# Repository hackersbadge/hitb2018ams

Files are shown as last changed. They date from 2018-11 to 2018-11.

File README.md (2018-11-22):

# Hacker's Badge for Hack In The Box 2018, Amsterdam

- [x] Hardware: WhiteA10n3
- [x] Code: KLKS + xwings (partial)

* MCU: STM32F103
* Flash: W25Q32
* 1.3 inch OLED
* 433Mhz RF Receiver
* IR Receiver
* 6 Buttons (Up, Down, Left, Right, OK, ESC)
* 6 x RGB LED

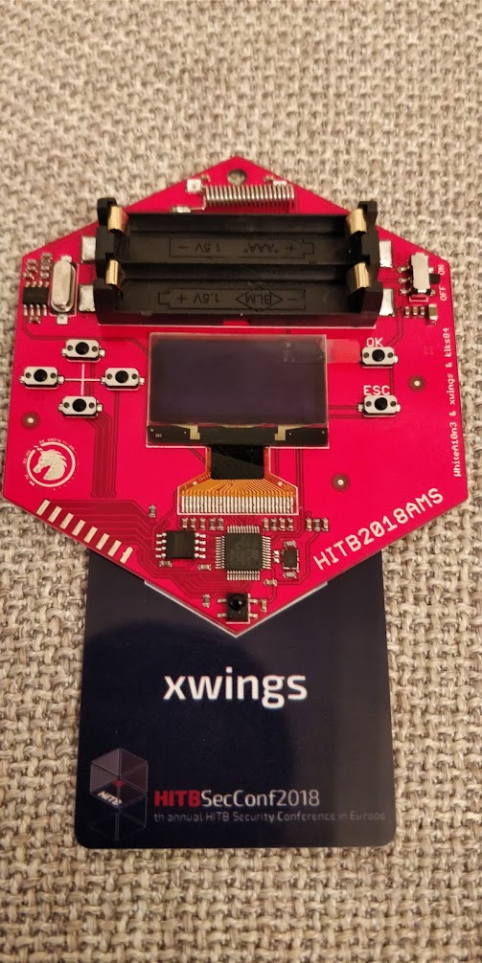
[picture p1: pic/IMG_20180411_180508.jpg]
badge0
      
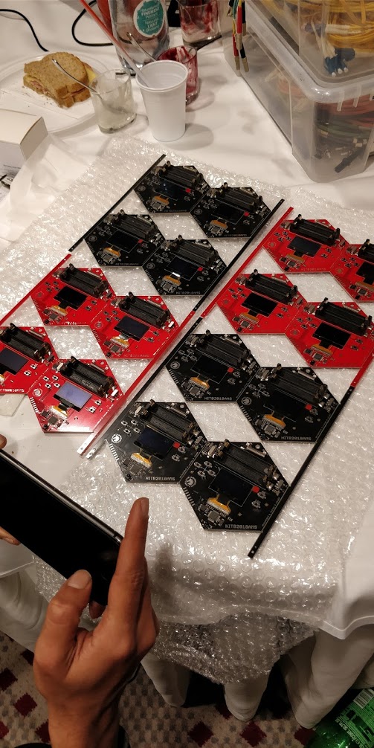
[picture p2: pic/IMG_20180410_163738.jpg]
badge1


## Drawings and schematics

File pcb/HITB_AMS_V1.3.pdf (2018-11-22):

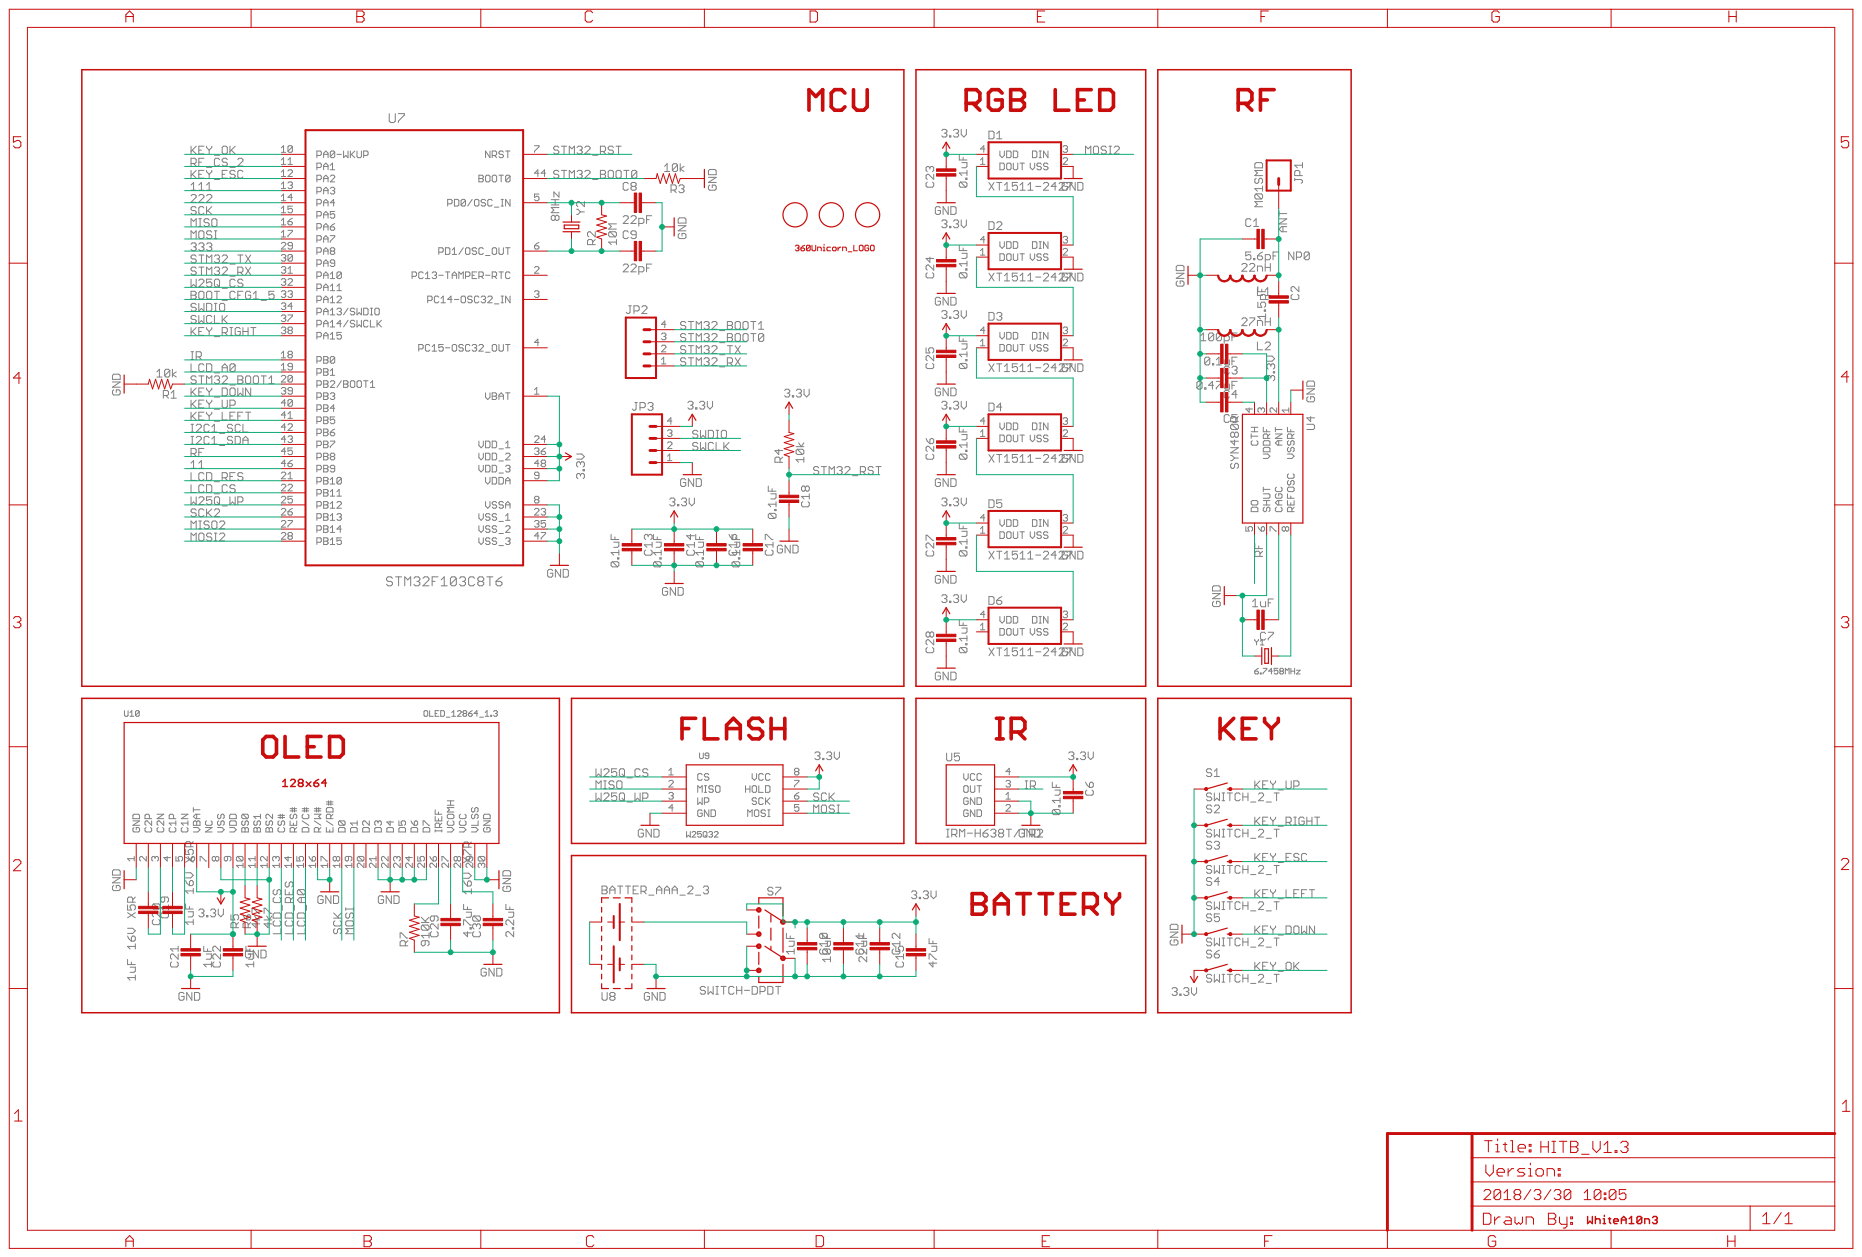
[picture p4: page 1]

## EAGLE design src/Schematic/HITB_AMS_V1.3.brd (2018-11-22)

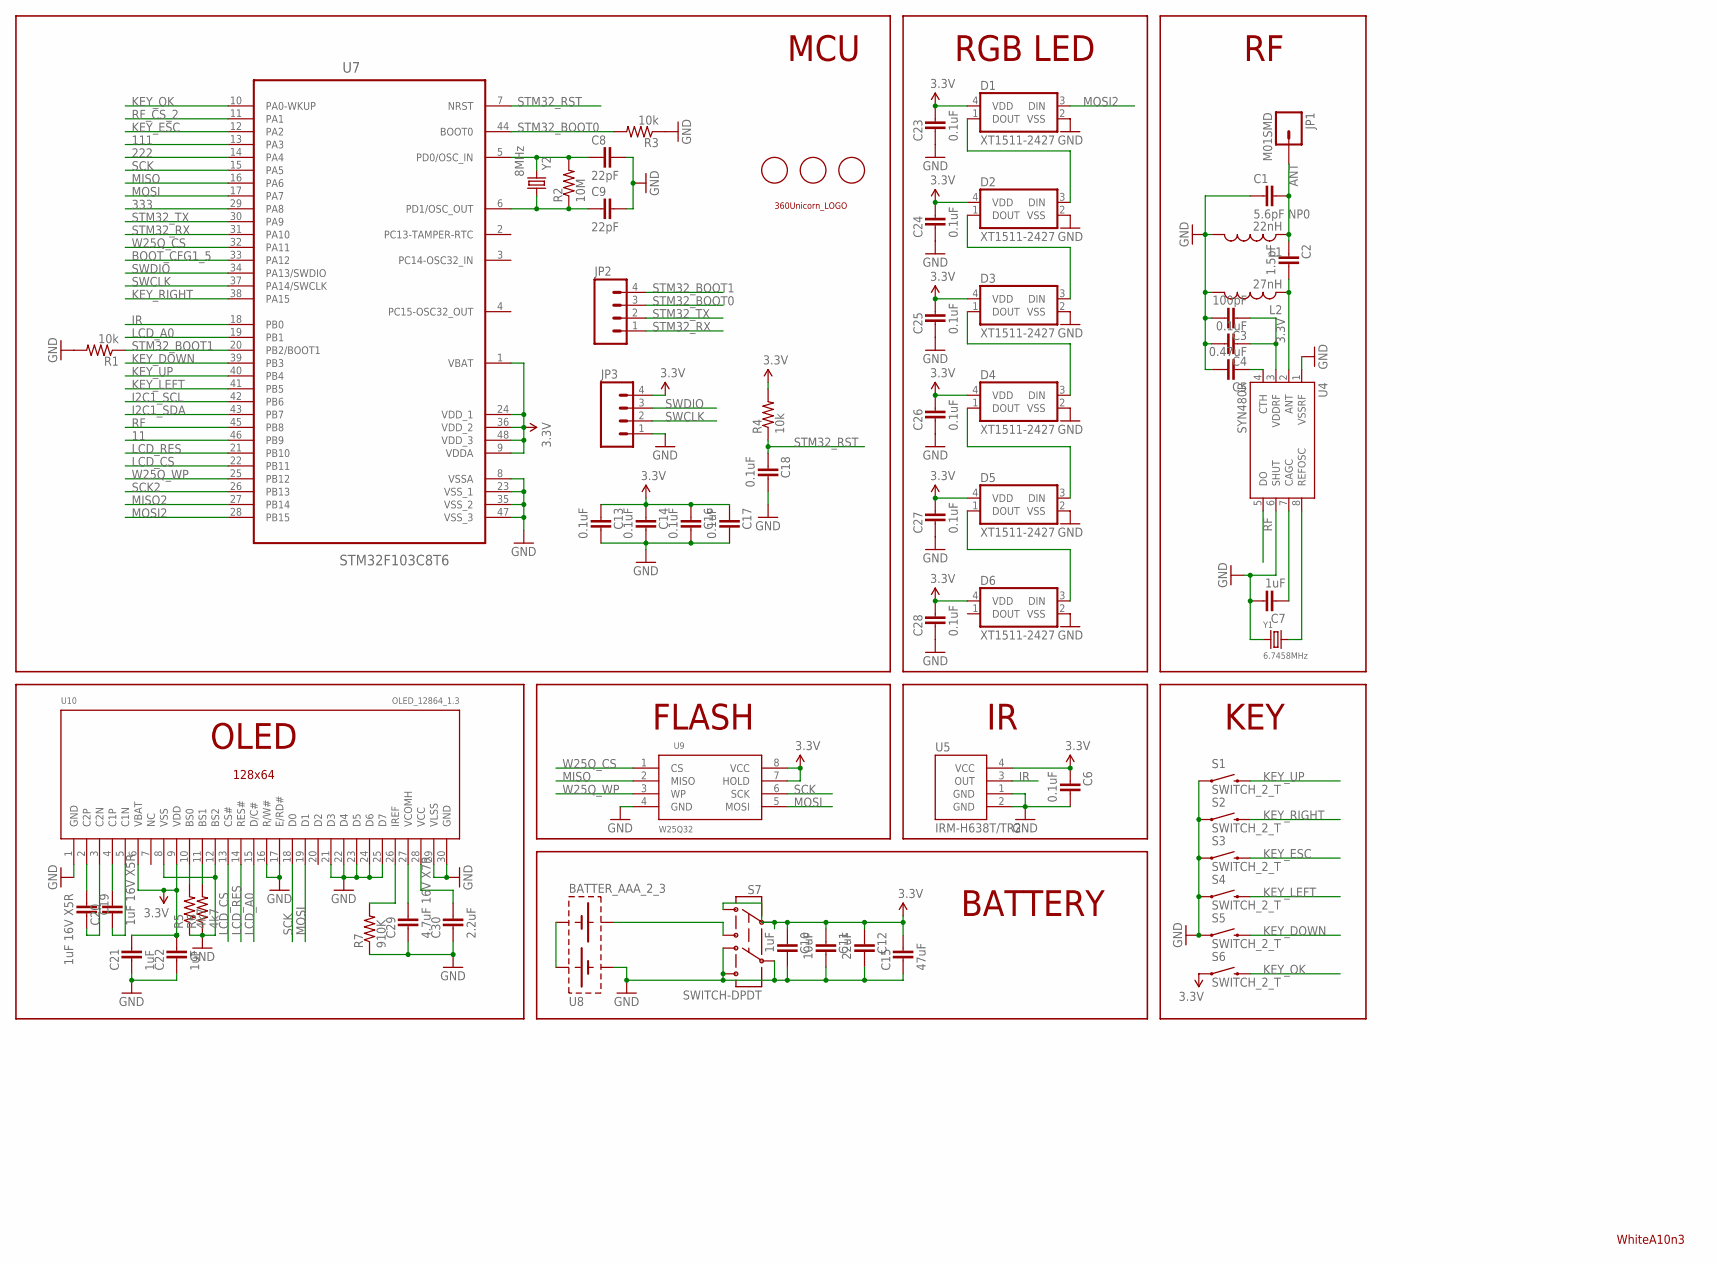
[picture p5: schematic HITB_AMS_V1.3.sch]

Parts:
C1: 5.6pF NP0; 0603-CAP
C2: 1.5pF; 0603-CAP
C3: 100pF; 0603-CAP
C4, C6, C13, C14, C16, C17, C18, C23, C24, C25, C26, C27, C28: 0.1uF; 0603-CAP
C5: 0.47uF; 0603-CAP
C7, C10, C21, C22: 1uF; 0603-CAP
C8, C9: 22pF; 0603-CAP
C11: 10uF; 0603-CAP
C12: 22uF; 0603-CAP
C15: 47uF; 1206
C19, C20: 1uF 16V X5R; 0603-CAP
C29: 4.7uF 16V X7R; 0603-CAP
C30: 2.2uF; 0603-CAP
D1, D2, D3, D4, D5, D6: XT1511-2427; RGB_2427
JP1: M01SMD; LUXEON-PAD
JP2, JP3: M04_TEST_2; 1X04_TEST_2
L1: 22nH; 0603
L2: 27nH; 0603
R1, R3, R4: 10k; 0603-RES
R2: 10M; 0603-RES
R5, R6: 4k7; 0603-RES
R7: 910K; 0603-RES
S1, S2, S3, S4, S5, S6: SWITCH_2_T; BUTTON_TSSURX
S7: SWITCH-DPDT; MSS22D18
U1, U2, U3: FIDUCIALMOUNT; FIDUCIA-MOUNT
U4: SYN480R; SO08
U5: IRM-H638T/TR2; IR_RECEIVE
U6: 360UNICORN_LOGO_0.8_STOP; 360UNICORN_S0.8
U7: STM32F103C8T6; TQFP48
U8: BATTER_AAA_2_3; BATTER_AAA_3
U9: W25Q32; SO08-EIAJ
U10: OLED_12864_1.3
Y1: 6.7458MHz; HC49UP
Y2: 8MHz; CRYSTAL-SMD-3225

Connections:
3.3V: C3.2, C4.2, C6.2, C10.2, C11.2, C12.2, C13.2, C14.2, C15.1, C16.2, C17.2, C21.1, C22.1, C23.1, C24.1, C25.1, C26.1, C27.1, C28.1, D1.4 (VDD), D2.4 (VDD), D3.4 (VDD), D4.4 (VDD), D5.4 (VDD), D6.4 (VDD), JP3.4, R4.2, S6.P$1 (1), S7.1, S7.2, U4.3 (VDDRF), U5.4 (VCC), U7.1 (VBAT), U7.9 (VDDA), U7.24 (VDD_1), U7.36 (VDD_2), U7.48 (VDD_3), U9.7 (HOLD), U9.8 (VCC), U10.6 (VBAT), U10.9 (VDD)
11: U7.46 (PB9)
111: U7.13 (PA3)
222: U7.14 (PA4)
333: U7.29 (PA8)
ANT: C1.1, C2.2, JP1.P$1, L1.1
BOOT_CFG1_5: U7.33 (PA12)
GND: C1.2, C3.1, C4.1, C5.1, C6.1, C7.1, C8.1, C9.1, C10.1, C11.1, C12.1, C13.1, C14.1, C15.2, C16.1, C17.1, C18.1, C21.2, C22.2, C23.2, C24.2, C25.2, C26.2, C27.2, C28.2, C29.2, C30.2, D1.2 (VSS), D2.2 (VSS), D3.2 (VSS), D4.2 (VSS), D5.2 (VSS), D6.2 (VSS), JP3.1, L1.2, L2.2, R1.2, R3.1, R5.1, R6.1, R7.1, S1.P$1 (1), S2.P$1 (1), S3.P$1 (1), S4.P$1 (1), S5.P$1 (1), S7.4, S7.5, S7.6, U4.1 (VSSRF), U4.6 (SHUT), U5.1 (GND), U5.2 (GND), U7.8 (VSSA), U7.23 (VSS_1), U7.35 (VSS_2), U7.47 (VSS_3), U8.A-, U9.4 (GND), U10.1 (GND), U10.8 (VSS), U10.12 (BS2), U10.16 (R/W#), U10.17 (E/RD#), U10.21 (D3), U10.22 (D4), U10.23 (D5), U10.24 (D6), U10.25 (D7), U10.29 (VLSS), U10.30 (GND), Y1.1
I2C1_SCL: U7.42 (PB6)
I2C1_SDA: U7.43 (PB7)
IR: U5.3 (OUT), U7.18 (PB0)
KEY_DOWN: S5.P$2 (2), U7.39 (PB3)
KEY_ESC: S3.P$2 (2), U7.12 (PA2)
KEY_LEFT: S4.P$2 (2), U7.41 (PB5)
KEY_OK: S6.P$2 (2), U7.10 (PA0-WKUP)
KEY_RIGHT: S2.P$2 (2), U7.38 (PA15)
KEY_UP: S1.P$2 (2), U7.40 (PB4)
LCD_A0: U7.19 (PB1), U10.15 (D/C#)
LCD_CS: U7.22 (PB11), U10.13 (CS#)
LCD_RES: U7.21 (PB10), U10.14 (RES#)
MISO: U7.16 (PA6), U9.2 (MISO)
MISO2: U7.27 (PB14)
MOSI: U7.17 (PA7), U9.5 (MOSI), U10.19 (D1)
MOSI2: D1.3 (DIN), U7.28 (PB15)
unnamed: D3.1 (DOUT), D4.3 (DIN)
unnamed: C8.2, R2.2, U7.5 (PD0/OSC_IN), Y2.1
unnamed: R5.2, U10.10 (BS0)
unnamed: C9.2, R2.1, U7.6 (PD1/OSC_OUT), Y2.3 (2)
unnamed: U8.A+, U8.B-
unnamed: D4.1 (DOUT), D5.3 (DIN)
unnamed: D5.1 (DOUT), D6.3 (DIN)
unnamed: S7.3, U8.B+
unnamed: C29.1, U10.27 (VCOMH)
unnamed: C19.2, U10.2 (C2P)
unnamed: C19.1, U10.3 (C2N)
unnamed: C20.1, U10.4 (C1P)
unnamed: C20.2, U10.5 (C1N)
unnamed: C30.1, U10.28 (VCC)
unnamed: R7.2, U10.26 (IREF)
unnamed: R6.2, U10.11 (BS1)
unnamed: C2.1, L2.1, U4.2 (ANT)
unnamed: C5.2, U4.4 (CTH)
unnamed: C7.2, U4.7 (CAGC)
unnamed: U4.8 (REFOSC), Y1.2
unnamed: D2.1 (DOUT), D3.3 (DIN)
unnamed: D1.1 (DOUT), D2.3 (DIN)
RF: U4.5 (DO), U7.45 (PB8)
RF_CS_2: U7.11 (PA1)
SCK: U7.15 (PA5), U9.6 (SCK), U10.18 (D0)
SCK2: U7.26 (PB13)
STM32_BOOT0: JP2.3, R3.2, U7.44 (BOOT0)
STM32_BOOT1: JP2.4, R1.1, U7.20 (PB2/BOOT1)
STM32_RST: C18.2, R4.1, U7.7 (NRST)
STM32_RX: JP2.1, U7.31 (PA10)
STM32_TX: JP2.2, U7.30 (PA9)
SWCLK: JP3.2, U7.37 (PA14/SWCLK)
SWDIO: JP3.3, U7.34 (PA13/SWDIO)
W25Q_CS: U7.32 (PA11), U9.1 (CS)
W25Q_WP: U7.25 (PB12), U9.3 (WP)

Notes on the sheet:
MCU
RGB LED
KEY
FLASH
BATTERY
WhiteA10n3

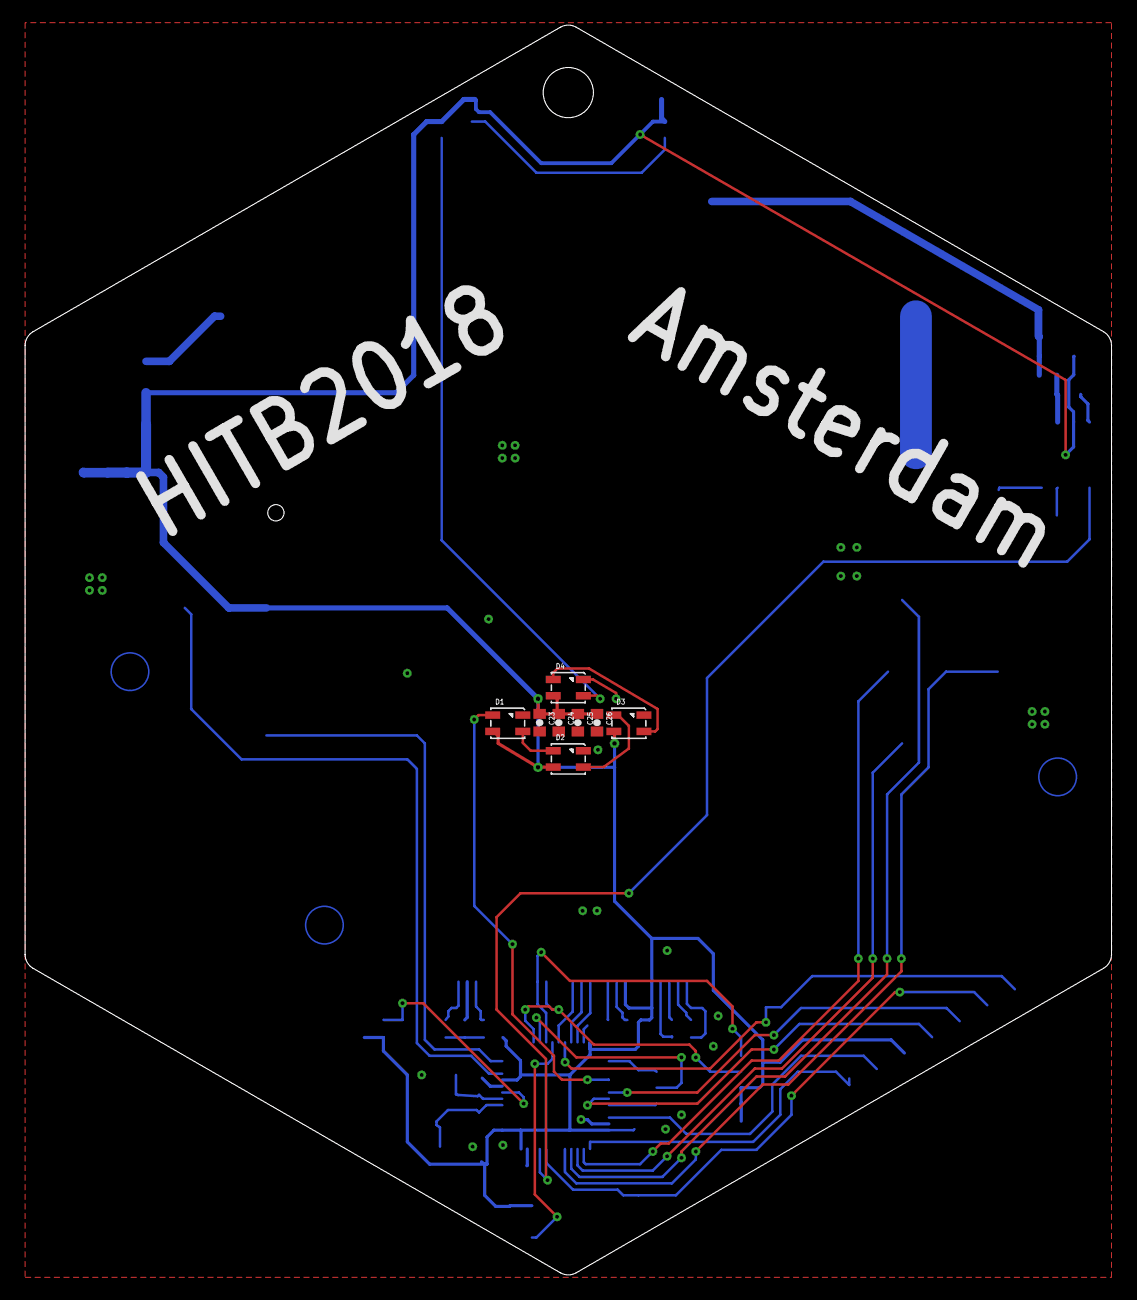
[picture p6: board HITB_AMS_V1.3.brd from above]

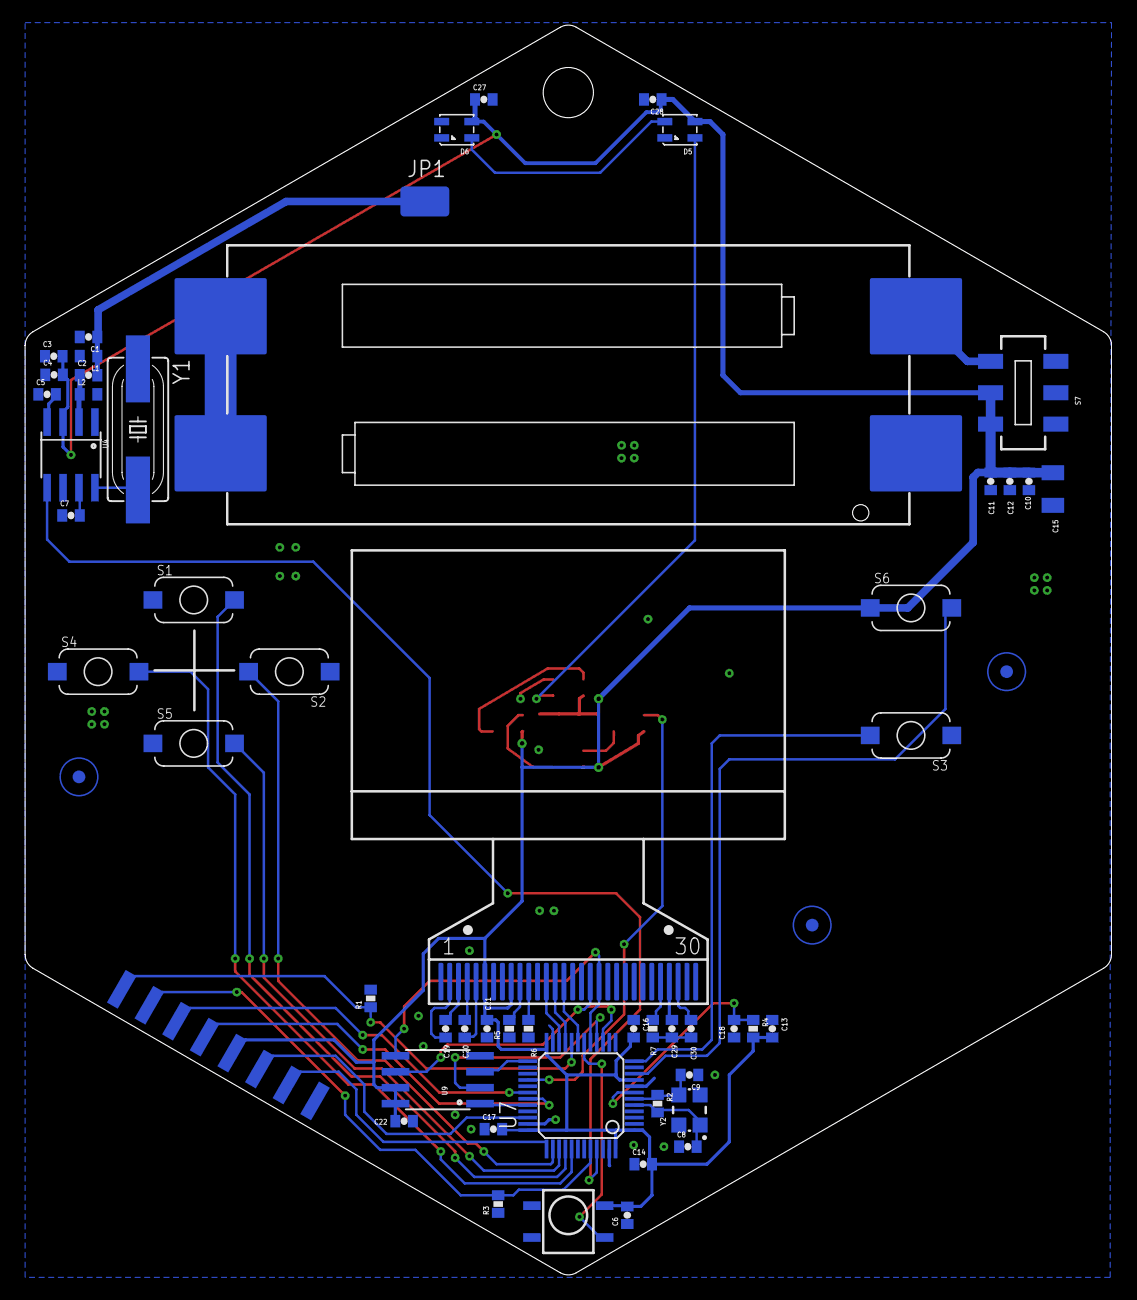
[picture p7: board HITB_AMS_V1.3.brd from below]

Board: 2 copper layers, 86.6 x 99.6 mm, 67 parts (59 on the bottom side), 49 nets.

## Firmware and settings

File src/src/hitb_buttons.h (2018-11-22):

//Buttons
#define button_up_pin PB4
#define button_down_pin PB3
#define button_left_pin PB5
#define button_right_pin PA15
#define button_ok_pin PA0
#define button_cancel_pin PA2

int button_up_state = LOW;
long button_up_ldt=millis();
int button_down_state = LOW;
long button_down_ldt=millis();
int button_left_state = LOW;
long button_left_ldt=millis();
int button_right_state = LOW;
long button_right_ldt=millis();
int button_ok_state = LOW;
long button_ok_ldt=millis();
int button_cancel_state = LOW;
long button_cancel_ldt=millis();

long debounceDelay = 50;

void button_ok_interrupt(){
  if( (millis() - button_ok_ldt ) > debounceDelay){
    button_ok_state = !button_ok_state;
    button_ok_ldt = millis();
  }
}

void button_cancel_interrupt(){
  if( (millis() - button_cancel_ldt ) > debounceDelay){
    button_cancel_state = !button_cancel_state;
    button_cancel_ldt = millis();
  }
}

void button_down_interrupt(){
  if( (millis() - button_down_ldt ) > debounceDelay){
    button_down_state = !button_down_state;
    button_down_ldt = millis();
  }
}

void button_up_interrupt(){
  if( (millis() - button_up_ldt ) > debounceDelay){
    button_up_state = !button_up_state;
    button_up_ldt = millis();
  }
}

void button_left_interrupt(){
  if( (millis() - button_left_ldt ) > debounceDelay){
    button_left_state = !button_left_state;
    button_left_ldt = millis();
  }
}

void button_right_interrupt(){
  if( (millis() - button_right_ldt ) > debounceDelay){
    button_right_state = !button_right_state;
    button_right_ldt = millis();
  }
}

void setup_buttons(){
  pinMode(button_up_pin, INPUT_PULLUP);
  pinMode(button_down_pin, INPUT_PULLUP);
  pinMode(button_left_pin, INPUT_PULLUP);
  pinMode(button_right_pin, INPUT_PULLUP);
  pinMode(button_ok_pin, INPUT_PULLDOWN);
  pinMode(button_cancel_pin, INPUT_PULLUP);

  attachInterrupt(digitalPinToInterrupt(button_up_pin), button_up_interrupt, CHANGE);
  attachInterrupt(digitalPinToInterrupt(button_down_pin), button_down_interrupt, CHANGE);
  attachInterrupt(digitalPinToInterrupt(button_left_pin), button_left_interrupt, CHANGE);
  attachInterrupt(digitalPinToInterrupt(button_right_pin), button_right_interrupt, CHANGE);
  attachInterrupt(digitalPinToInterrupt(button_ok_pin), button_ok_interrupt, CHANGE);
  attachInterrupt(digitalPinToInterrupt(button_cancel_pin), button_cancel_interrupt, CHANGE);
}

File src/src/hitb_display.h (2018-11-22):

#pragma once

extern int button_cancel_state;

#include <Adafruit_GFX.h>
#include <Adafruit_SSD1306.h>
#include "qrcode.h"

// If using software SPI (the default case):
#define OLED_MOSI  PA7
#define OLED_CLK   PA5
#define OLED_DC    PB1
#define OLED_CS    PB11
#define OLED_RESET PB10

Adafruit_SSD1306 display(OLED_MOSI, OLED_CLK, OLED_DC, OLED_RESET, OLED_CS);

#if (SSD1306_LCDHEIGHT != 64)
#error("Height incorrect, please fix Adafruit_SSD1306.h!");
#endif

void setup_display(){
  // by default, we'll generate the high voltage from the 3.3v line internally! (neat!)
  display.begin(SSD1306_SWITCHCAPVCC);
  display.setTextWrap(false);
}

void wake_display(){
  display.dim(false);
}

void sleep_display(){
  display.clearDisplay();
  display.dim(true);
  display.display();
}

boolean delay_interuptable(int wait_time){
  for(int i=0; i < wait_time; i++){
    if(button_cancel_state) return false;
    delay(1);
  }
  return true;
}

//https://github.com/ricmoo/QRCode/blob/master/examples/QRCode/QRCode.ino
void display_qrcode(const char *data){
  QRCode qrcode;
  uint8_t qrcodeData[qrcode_getBufferSize(3)];

  qrcode_initText(&qrcode, qrcodeData, 3, ECC_HIGH, data);
  
  display.clearDisplay();
  display.fillRect(35, 0, 62, 64, WHITE);
  int x_offset = 37, y_offset = 3;
  for(uint8_t y = 0; y < qrcode.size; y++){
    for(uint8_t x = 0; x < qrcode.size; x++){
      if(qrcode_getModule(&qrcode, x, y)){
        //display.drawPixel(x_offset + x, y_offset + y, BLACK);
        display.drawPixel(x_offset + (x*2), y_offset + (y*2), BLACK);
        display.drawPixel(x_offset +(x*2)+1, y_offset + (y*2), BLACK);
        display.drawPixel(x_offset + (x*2)+1, y_offset + (y*2)+1, BLACK);
        display.drawPixel(x_offset + (x*2), y_offset + (y*2)+1, BLACK);
      }
    }
  }
  display.display();
  while(delay_interuptable(1000));
  delay(200); //Let buttons settle down
}

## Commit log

2018-11-22 initial commit for amsterdam
    [HITB_AMS_V1.3.brd, HITB_AMS_V1.3.sch]
2018-11-22 added source
    [HITB_AMS_V1.3.brd, HITB_AMS_V1.3.sch]

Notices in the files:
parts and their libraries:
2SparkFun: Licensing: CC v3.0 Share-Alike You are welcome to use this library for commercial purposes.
